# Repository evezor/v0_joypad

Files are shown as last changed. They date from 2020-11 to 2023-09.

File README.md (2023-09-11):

# Joypad Edge Board
*please note this board has been deprecated.

An edge board shaped like a joypad. It has 2 analog inputs, 4 light up buttons, start and select pushbuttons, a dpad, a buzzer and a 5 position neopixel strip. 

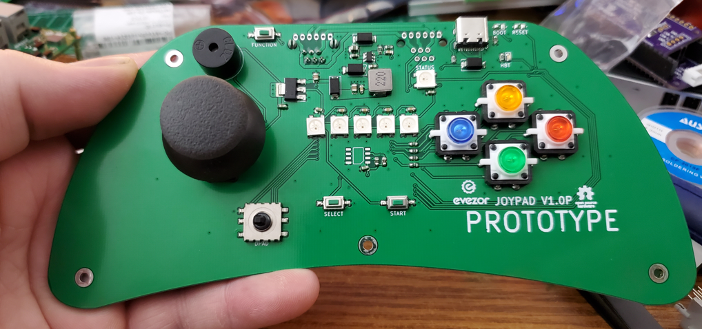
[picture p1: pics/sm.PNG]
sm


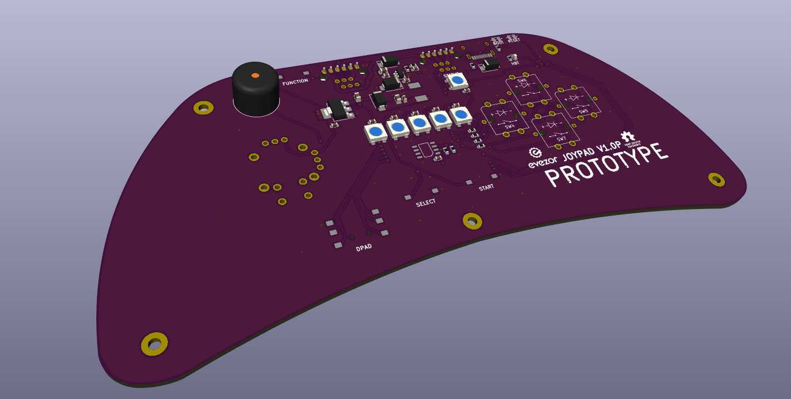
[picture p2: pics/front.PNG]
front


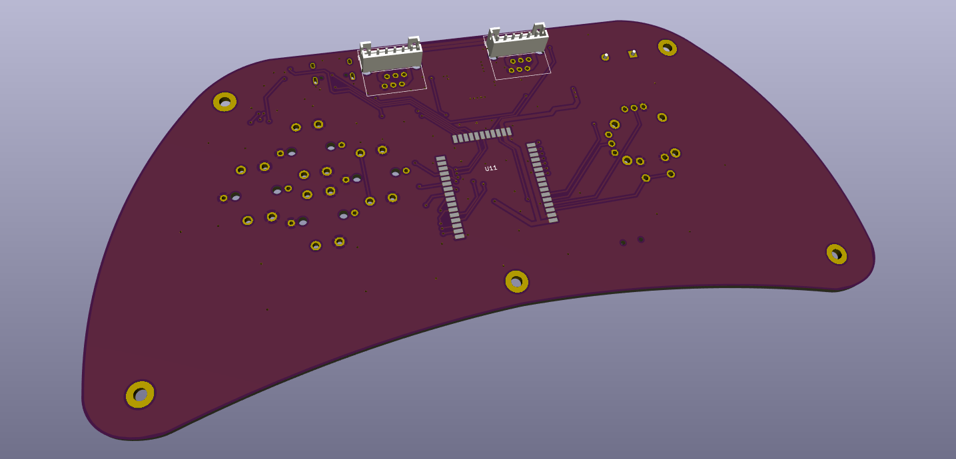
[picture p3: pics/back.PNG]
back


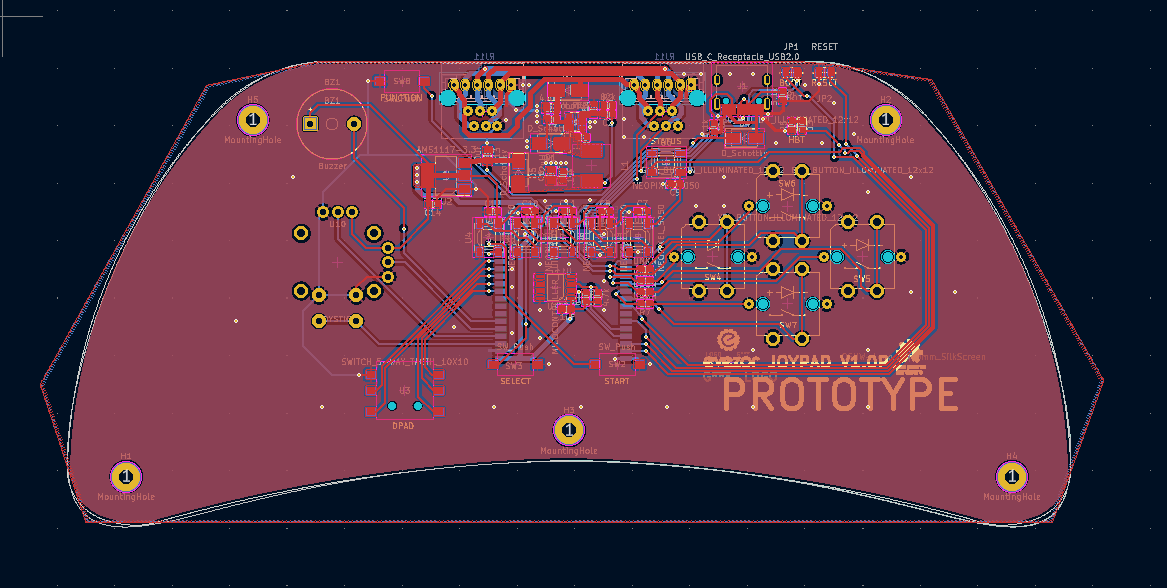
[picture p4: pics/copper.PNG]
copper


sch

source files can be found here: https://github.com/evezor/v0_joypad

This board uses the Evezor Stamp STMF405 MCU

source: https://github.com/evezor/Evezor-Stamp-STMF405

Evezor® and all associated marks, logos, and designs are registered trademarks and protected by copyright. Unauthorized use or reproduction of these trademarks and copyrighted materials is strictly prohibited.

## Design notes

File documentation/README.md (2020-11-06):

There are no significant components to share on this board

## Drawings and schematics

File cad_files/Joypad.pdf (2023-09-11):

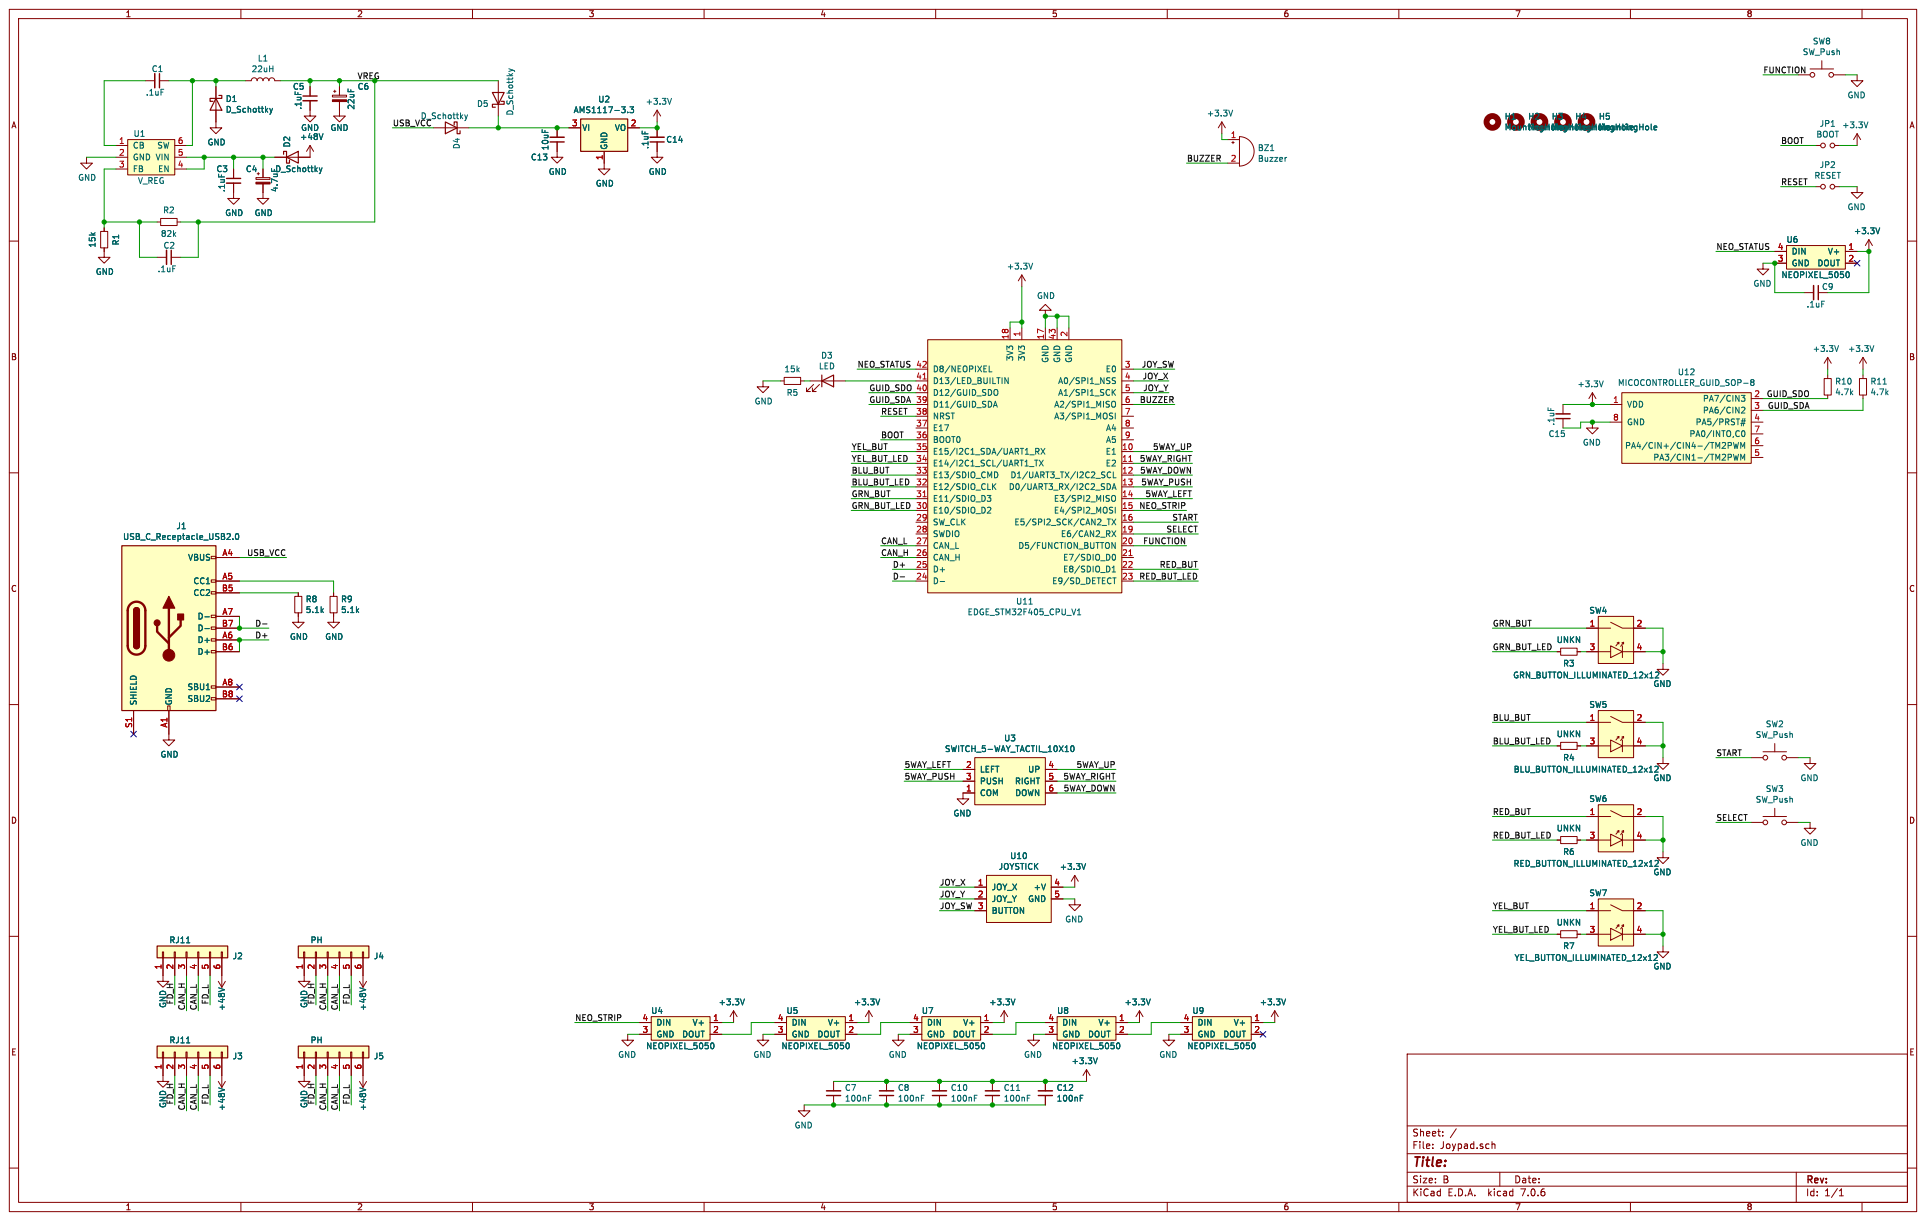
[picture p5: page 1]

1 VO 2 VI 3 U2 AMS1117-3.3 GND GND

1 VO 2 VI 3 GND GND

2 D5/FUNCTION_BUTTON 20 E7/SDIO_D0 21 E8/SDIO_D1 22 E9/SD_DETECT 23 D- 24 D+ 25 CAN_H 26 CAN_L 27 SWDIO 28 SW_CLK 29 E0 3 E10/SDIO_D2 30 E11/SDIO_D3 31 E12/SDIO_CLK 32 E13/SDIO_CMD 33 E14/I2C1_SCL/UART1_TX 34 E15/I2C1_SDA/UART1_RX 35 BOOT0 36 E17 37 NRST 38 D11/GUID_SDA 39 A0/SPI1_NSS 4 D12/GUID_SDO 40 D13/LED_BUILTIN 41 D8/NEOPIXEL 42 GND 43 A1/SPI1_SCK 5 A2/SPI1_MISO 6 A3/SPI1_MOSI 7 A4 8 A5 9 U11 EDGE_STM32F405_CPU_V1 C2

6 GND +48V U5 NEOPIXEL_5050 V+ 1 DOUT 2 GND 3 DIN 4 +3.3V U4 NEOPIXEL_5050 V+ 1 DOUT 2 GND 3 DIN 4 +3.3V U10

100nFV+ 1 DOUT 2 GND 3 DIN 4 U7 NEOPIXEL_5050 GND

Id: 1/1 Title: File: Joypad.sch Sheet: /

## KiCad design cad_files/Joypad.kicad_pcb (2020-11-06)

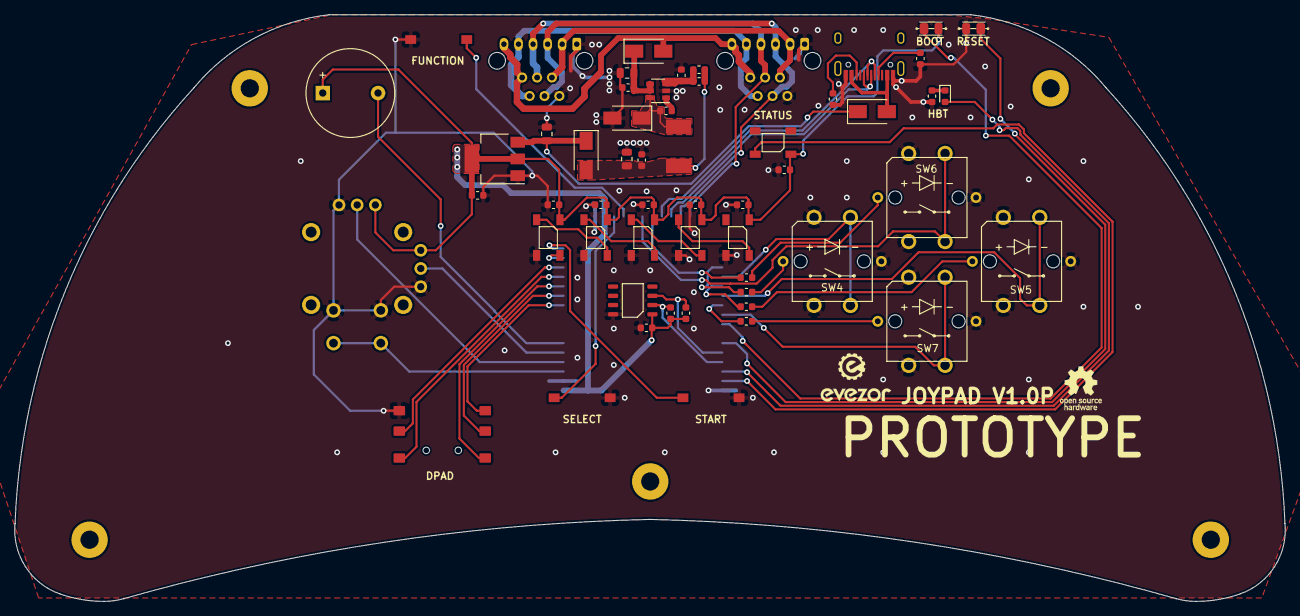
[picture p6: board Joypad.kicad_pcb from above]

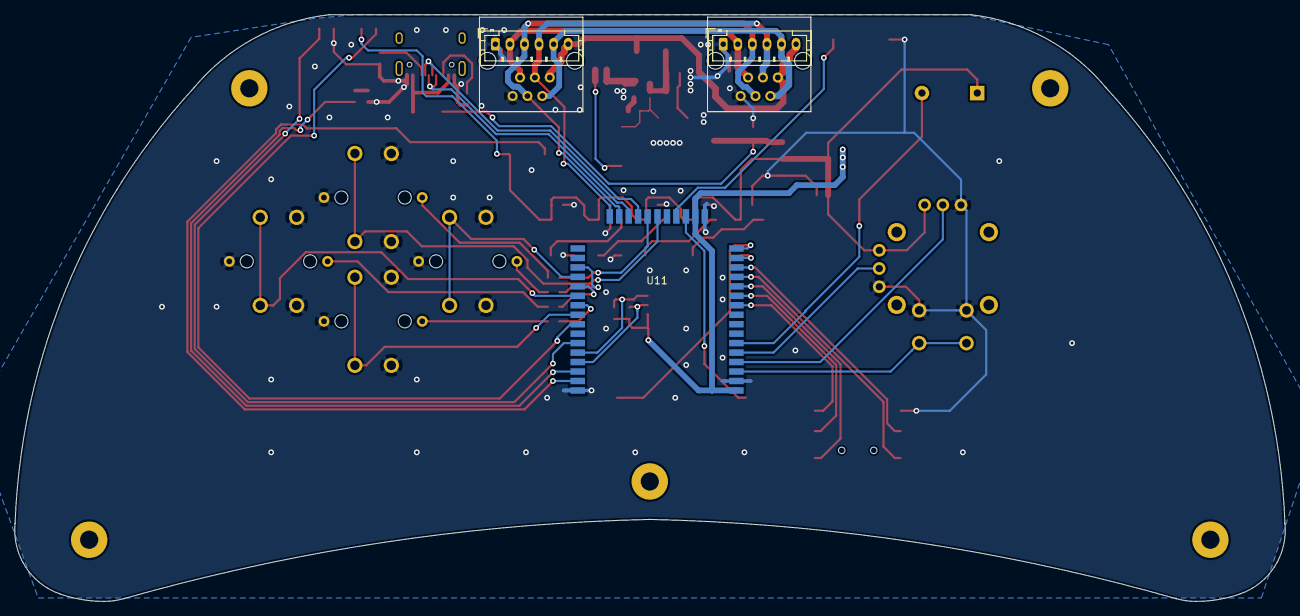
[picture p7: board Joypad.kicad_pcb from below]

Board: 2 copper layers, 174.5 x 80.6 mm, 64 parts (5 on the bottom side), 54 nets.

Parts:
BZ1: Buzzer; Buzzer_12x9.5RM7.6
C1, C2, C3, C5, C9, C14, C15: .1uF; C_0603_1608Metric
C4: 4.7uF; C_0805_2012Metric
C6: 22uF; C_0805_2012Metric
C7, C8, C10, C11, C12: 100nF; C_0603_1608Metric
C13: 10uF; C_0805_2012Metric
D1, D2, D4, D5: D_Schottky; D_SMA
D3: LED; LED_0603_1608Metric
H1, H2, H3, H4, H5: MountingHole; MountingHole_2.5mm_Pad
J1: USB_C_Receptacle_USB2.0; USB_C_Receptacle_HRO_TYPE-C-31-M-12
J2, J3: RJ11; RJ11_C189747_Horizontal
J4, J5: PH; JST_PH_B6B-PH-K_1x06_P2.00mm_Vertical
JP1: BOOT; SHORT_PAD
JP2: RESET; SHORT_PAD
L1: 22uH; INDUCTOR_7.5X6.6_GCDA0630-220MC
R1, R5: 15k; R_0603_1608Metric
R2: 82k; R_0603_1608Metric
R3, R4, R6, R7: UNKN; R_0603_1608Metric
R8, R9: 5.1k; R_0603_1608Metric
R10, R11: 4.7k; R_0603_1608Metric
SW2, SW3, SW8: SW_Push; SWITCH_2x3_SMD_TACTILE_GREEN
SW4: GRN_BUTTON_ILLUMINATED_12x12; Illuminated_Round_Button
SW5: BLU_BUTTON_ILLUMINATED_12x12; Illuminated_Round_Button
SW6: RED_BUTTON_ILLUMINATED_12x12; Illuminated_Round_Button
SW7: YEL_BUTTON_ILLUMINATED_12x12; Illuminated_Round_Button
U1: V_REG; SOT-23-6
U2: AMS1117-3.3; SOT-223-3_TabPin2
U3: SWITCH_5-WAY_TACTIL_10X10; SWITCH_5WAY_10x10
U4, U5, U6, U7, U8, U9: NEOPIXEL_5050
U10: JOYSTICK
U11: EDGE_STM32F405_CPU_V1; EDGE_STAMP
U12: MICOCONTROLLER_GUID_SOP-8; GUID_PS150C

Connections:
+3V3: BZ1.1, C7.2, C8.2, C9.1, C10.2, C11.2, C12.2, C14.2, C15.2, JP1.2, R10.1, R11.1, U2.2, U4.1, U5.1, U6.1, U7.1, U8.1, U9.1, U10.4, U11.1, U11.18, U12.1
+48V: D2.2, J2.6, J3.6, J4.6, J5.6
/5WAY_DOWN: U3.6, U11.12
/5WAY_LEFT: U3.2, U11.14
/5WAY_PUSH: U3.3, U11.13
/5WAY_RIGHT: U3.5, U11.11
/5WAY_UP: U3.4, U11.10
/BLU_BUT: SW5.1, U11.33
/BLU_BUT_LED: R4.2, U11.32
/BOOT: JP1.1, U11.36
/BUZZER: BZ1.2, U11.6
/CAN_H: J2.3, J3.3, J4.3, J5.3, U11.26
/CAN_L: J2.4, J3.4, J4.4, J5.4, U11.27
/D+: J1.A6, J1.B6, U11.25
/D-: J1.A7, J1.B7, U11.24
/FD_H: J2.2, J3.2, J4.2, J5.2
/FD_L: J2.5, J3.5, J4.5, J5.5
/FUNCTION: SW8.1, U11.20
/GRN_BUT: SW4.1, U11.31
/GRN_BUT_LED: R3.2, U11.30
/GUID_SDA: R11.2, U11.39, U12.3
/GUID_SDO: R10.2, U11.40, U12.2
/JOY_SW: U10.3, U11.3
/JOY_X: U10.1, U11.4
/JOY_Y: U10.2, U11.5
/NEO_STATUS: U6.4, U11.42
/NEO_STRIP: U4.4, U11.15
/RED_BUT: SW6.1, U11.22
/RED_BUT_LED: R6.2, U11.23
/RESET: JP2.1, U11.38
/SELECT: SW3.1, U11.19
/START: SW2.1, U11.16
/USB_VCC: D4.2, J1.A4, J1.A9, J1.B4, J1.B9
/VREG: C2.1, C5.1, C6.1, D5.2, L1.2, R2.1
/YEL_BUT: SW7.1, U11.35
/YEL_BUT_LED: R7.2, U11.34
GND: C3.2, C4.2, C5.2, C6.2, C7.1, C8.1, C9.2, C10.1, C11.1, C12.1, C13.1, C14.1, C15.1, D1.2, J1.A1, J1.A12, J1.B1, J1.B12, J2.1, J3.1, J4.1, J5.1, JP2.2, R1.1, R5.1, R8.2, R9.2, SW2.2, SW3.2, SW4.2, SW4.4, SW5.2, SW5.4, SW6.2, SW6.4, SW7.2, SW7.4, SW8.2, U1.2, U2.1, U3.1, U4.3, U5.3, U6.3, U7.3, U8.3, U9.3, U10.5, U11.2, U11.17, U11.43, U12.8
unnamed: C1.1, D1.1, L1.1, U1.6
unnamed: C1.2, U1.1
unnamed: C2.2, R1.2, R2.2, U1.3
unnamed: C3.1, C4.1, D2.1, U1.4, U1.5
unnamed: C13.2, D4.1, D5.1, U2.3
unnamed: D3.1, R5.2
unnamed: D3.2, U11.41
unnamed: J1.A5, R9.1
unnamed: J1.B5, R8.1
unnamed: R3.1, SW4.3
unnamed: R4.1, SW5.3
unnamed: R6.1, SW6.3
unnamed: R7.1, SW7.3
unnamed: U4.2, U5.4
unnamed: U5.2, U7.4
unnamed: U7.2, U8.4
unnamed: U8.2, U9.4

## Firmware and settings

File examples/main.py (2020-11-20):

#Joypad v1.0p test code

from machine import Pin
from pyb import CAN, ADC, Timer
import utime

utime.sleep_ms(500)
print("starting Joypad v1.0p test code")
print("v1.0")
print("initializing")
can = CAN(1, CAN.NORMAL)
can.setfilter(0, CAN.LIST16, 0, (123, 124, 125, 126))


#Setup Pins
hbt_led = Pin("D13", Pin.OUT)
func_butt = Pin("D5", Pin.IN, Pin.PULL_UP)
can_wakeup = Pin("D6", Pin.OUT)
can_wakeup.value(0) 

X_POT = ADC("A0")
Y_POT = ADC("A1")

START_BUTTON = Pin("E5", Pin.IN, Pin.PULL_UP)
SELECT_BUTTON = Pin("E6", Pin.IN, Pin.PULL_UP)
GREEN_BUTTON = Pin("E15", Pin.IN, Pin.PULL_UP)
YELLOW_BUTTON = Pin("E8", Pin.IN, Pin.PULL_UP)
RED_BUTTON = Pin("E13", Pin.IN, Pin.PULL_UP)
BLUE_BUTTON = Pin("E11", Pin.IN, Pin.PULL_UP)

UP_BUTTON = Pin("E1", Pin.IN, Pin.PULL_UP)
DOWN_BUTTON = Pin("D1", Pin.IN, Pin.PULL_UP)
LEFT_BUTTON = Pin("E3", Pin.IN, Pin.PULL_UP)
RIGHT_BUTTON = Pin("E2", Pin.IN, Pin.PULL_UP)
PUSH_BUTTON = Pin("D0", Pin.IN, Pin.PULL_UP)

JOY_BUTTON = Pin("E0", Pin.IN, Pin.PULL_UP)

BUZZER_PIN = Pin('A2')

BUZZER_FREQ = Timer(3, freq = 240)
buzzer = BUZZER_FREQ.channel(1, Timer.PWM, pin=BUZZER_PIN)
buzzer.pulse_width_percent(0)
BUZZER_FREQ.deinit()

#Setup leds
BLUE_LED = Pin("E10", Pin.OUT)
RED_LED = Pin("E12", Pin.OUT)
YELLOW_LED = Pin("SD_DETECT", Pin.OUT)
GREEN_LED = Pin("E14", Pin.OUT)
    
#Setup hbt timer
hbt_state = 0
hbt_interval = 500
start = utime.ticks_ms()
next_hbt = utime.ticks_add(start, hbt_interval)
hbt_led.value(hbt_state)


print("starting")


def chk_hbt():
    global next_hbt
    global hbt_state
    now = utime.ticks_ms()
    if utime.ticks_diff(next_hbt, now) <= 0:
        if hbt_state == 1:
            hbt_state = 0
            hbt_led.value(hbt_state)
            #print("hbt")
        else:
            hbt_state = 1
            hbt_led.value(hbt_state)  
        
        next_hbt = utime.ticks_add(next_hbt, hbt_interval)

def chk_buttons():
    global next_button_chk
    now = utime_ms()
    if utime.ticks_diff(next_button_chk, now) <= 0:
        pass
        

def send():
    can.send('JOYPAD', 123)   # send a message with id 123
    
def get():
    mess = can.recv(0)
    print(mess)
    do_animation()
    do_animation()
    do_animation()
    do_animation()

def do_animation():
    BLUE_LED.value(1)
    utime.sleep_ms(100)
    BLUE_LED.value(0)
    utime.sleep_ms(100)
    RED_LED.value(1)
    utime.sleep_ms(100)
    RED_LED.value(0)
    utime.sleep_ms(100)
    YELLOW_LED.value(1)
    utime.sleep_ms(100)
    YELLOW_LED.value(0)
    utime.sleep_ms(100)
    GREEN_LED.value(1)
    utime.sleep_ms(100)
    GREEN_LED.value(0)
    utime.sleep_ms(100)

while True:
    chk_hbt()
    if not (func_butt.value()):
        print("function button")
        send()
        utime.sleep_ms(200)
    
    if can.any(0):
        get()

    if not (START_BUTTON.value()):
        print("START_BUTTON button:", X_POT.read(), Y_POT.read())
        utime.sleep_ms(200)

    if not (SELECT_BUTTON.value()):
        print("SELECT_BUTTON button")
        BUZZER_FREQ = Timer(3, freq = 52)
        buzzer = BUZZER_FREQ.channel(1, Timer.PWM, pin=BUZZER_PIN)
        buzzer.pulse_width_percent(30)
        utime.sleep_ms(100)
        BUZZER_FREQ.freq(200)
        utime.sleep_ms(100)
        BUZZER_FREQ.freq(400)
        utime.sleep_ms(100)
        BUZZER_FREQ.freq(800)
        utime.sleep_ms(100)
        BUZZER_FREQ.freq(1000)
        utime.sleep_ms(100)
        BUZZER_FREQ.freq(1200)
        utime.sleep_ms(100)
        BUZZER_FREQ.freq(1500)
        BUZZER_FREQ.deinit()
        
    if not (GREEN_BUTTON.value()):
        print("GREEN_BUTTON button")
        utime.sleep_ms(200)
        
    if not (RED_BUTTON.value()):
        print("RED_BUTTON button")
        utime.sleep_ms(200)
        
    if not (YELLOW_BUTTON.value()):
        print("YELLOW_BUTTON button")
        utime.sleep_ms(200)
        
    if not (BLUE_BUTTON.value()):
        print("BLUE_BUTTON button")
        utime.sleep_ms(200)
        
    if not (UP_BUTTON.value()):
        print("UP_BUTTON button")
        utime.sleep_ms(200)
            
    if not (DOWN_BUTTON.value()):
        print("DOWN_BUTTON button")
        utime.sleep_ms(200)

    if not (LEFT_BUTTON.value()):
        print("LEFT_BUTTON button")
        utime.sleep_ms(200)

    if not (RIGHT_BUTTON.value()):
        print("RIGHT_BUTTON button")
        utime.sleep_ms(200)
        
    if not (PUSH_BUTTON.value()):
        print("PUSH_BUTTON button")
        utime.sleep_ms(200)

    if not (JOY_BUTTON.value()):
        print("JOY_BUTTON button")
        utime.sleep_ms(200)



        
